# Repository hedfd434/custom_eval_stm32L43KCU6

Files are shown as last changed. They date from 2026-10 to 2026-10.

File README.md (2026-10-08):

# Custom evaluation board for stm32L432KCU6

This is a project of the custom evalution board for stm32L432KCU6.
The eval board was created for future test and prototypin during "2025/26 can-sat 🛰️ competition" organisated by ESA 🇪🇺 (European Space Agency), simultaneously it is a part of our PDR report 📑 (Preeliminary Desing Report).
By creating this board we want to show our capabilities in terms of electronics manufacturing ⚡📟.

<div style="display: flex; justify-content: center; gap: 20px;">
  <figure>
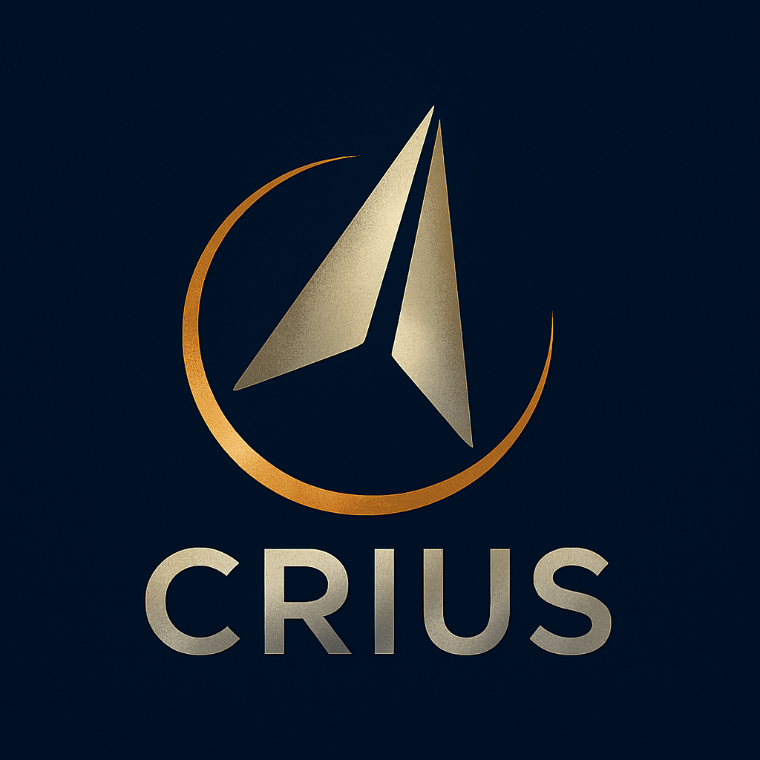
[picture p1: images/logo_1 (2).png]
    
    <figcaption style="text-align: center;">Logo of my team "Crius SPACE"</figcaption>
  </figure>
  <figure>
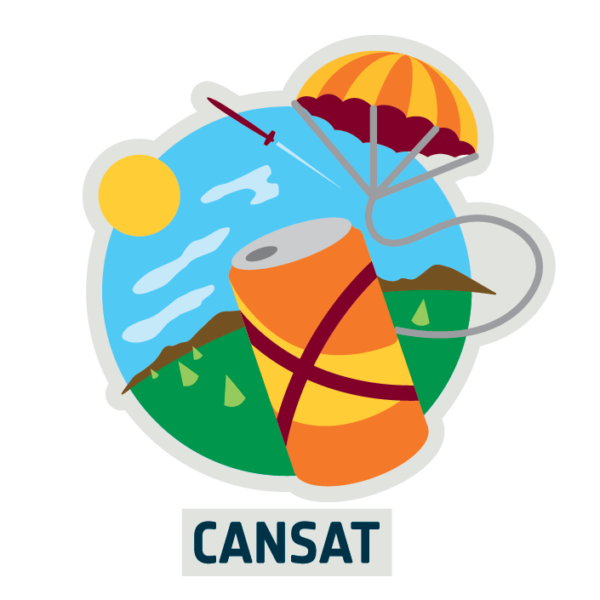
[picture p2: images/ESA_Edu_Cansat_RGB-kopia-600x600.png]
    
    <figcaption style="text-align: center;">We are taking part in can-sat competition by ESA</figcaption>
  </figure>
</div>

<div style="display: flex; justify-content: center; gap: 20px;">
  <figure>
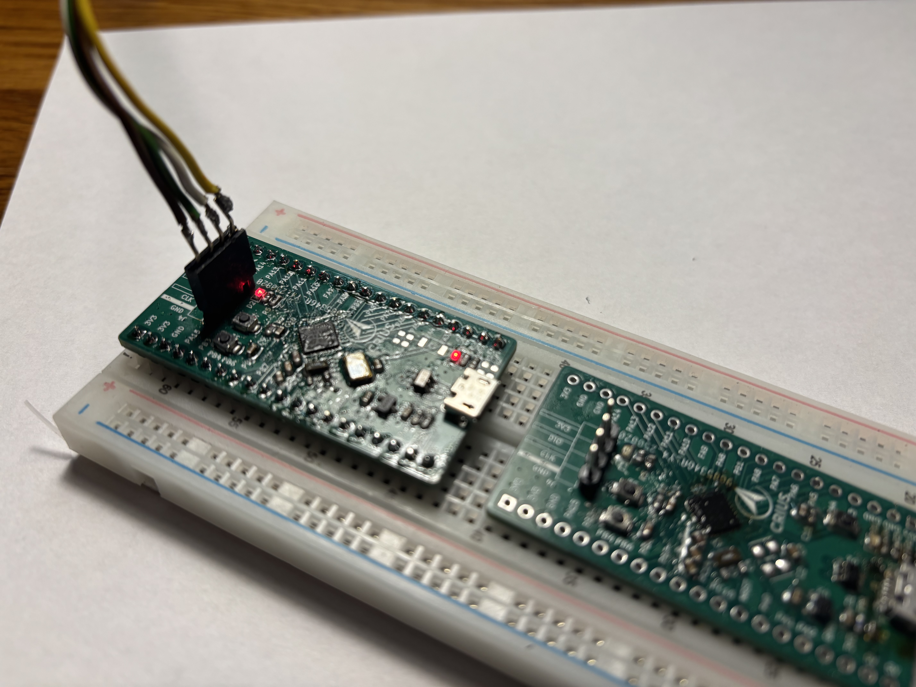
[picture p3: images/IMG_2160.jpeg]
    
    <figcaption style="text-align: center;">Real images of soldered board (running code)</figcaption>
  </figure>
  <figure>
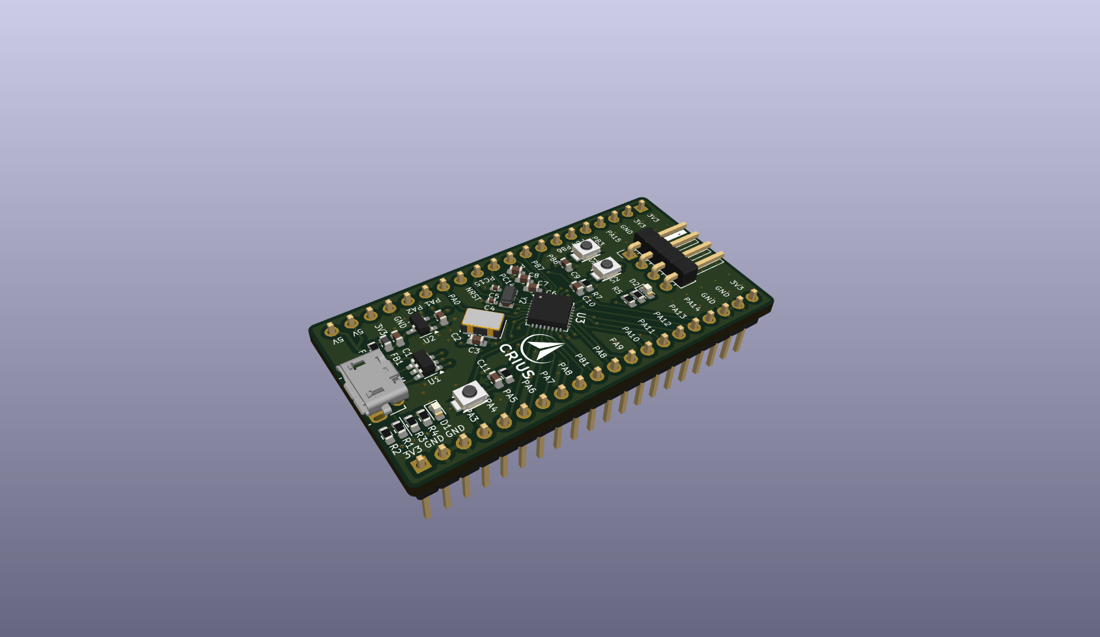
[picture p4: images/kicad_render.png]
    
    <figcaption style="text-align: center;">Render of the board in KiCAD</figcaption>
  </figure>
</div>

## future improvements, known issues and thing which are not tested
### known issues ⚠️❗:
- missing labels  - ()

- too small package - the capacitors for the LSE (Y2) are in size of 0402, (especially during manual soldering using hot-air gun or either conventional soldering iron (0603 is ratiobale limit for the size))

- space usage - board is bigger than the most popular eval boards like "blue/black pill" ❗

### probabable issues (not tested) ⚠️❗:
- reversd ESD protection for the usb (it is not necessary to use it)

### future improvements 📈🚀:
- components - no smaller than 0603 for manual soldering

- silk layer labels - complete silk layer labels

## customisation options ⚙️🛠️:
- as you can see on the photos of the real not everything is soldered:
1. 0ohm reistor on every diode - it allows you to reduce power usage in battery base aplications 🔋🪫.

2. 0ohm resistors on signal pins for usb - allows user to use pins in 2 different ways.

3. extra user button - with pull-up resistor and place for anit-debounce capacitor.

## extra files 📂:
1. stm32l432kcu6_eval_part_list.csv - file which contains list of the used elements with quantities for 1 board.

2. documentation folder - (in progress) folder which contains documentation for every component used in the project.

3. production_file_1.zip and production_file_1 - production ready files with current version of the project

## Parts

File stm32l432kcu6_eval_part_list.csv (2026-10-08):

Reference | Value | Datasheet | Footprint | Qty | LINK
C1,C2,C3,C8,C9,C10,C11 | 100nF | ~ | Capacitor_SMD:C_0603_1608Metric | 7 | https://www.tme.eu/pl/details/grm033r6ya104ke14d/kondensatory-mlcc-smd/murata/
C4,C5 | 20pF | ~ | Capacitor_SMD:C_0402_1005Metric | 2 | https://www.tme.eu/pl/details/gjm1555c1h200fb01d/kondensatory-mlcc-smd/murata/
C6 | 4.7uF | ~ | Capacitor_SMD:C_0603_1608Metric | 1 | https://www.tme.eu/pl/details/grm188r6ya475ke15d/kondensatory-mlcc-smd/murata/
C7 | 1uF | ~ | Capacitor_SMD:C_0603_1608Metric | 1 | https://www.tme.eu/pl/details/gcm188r71e105ka64d/kondensatory-mlcc-smd/murata/
D1,D2 | LED | ~ | LED_SMD:LED_0603_1608Metric | 2 | null (different colours)
F1 | 250mA | ~ | Fuse:Fuse_0603_1608Metric | 1 | https://www.tme.eu/pl/en/details/tr-0603fa250-r/0603-smd-fuses-ultra-fast/eaton-bussmann/
FB1 | value | ~ | Inductor_SMD:L_0603_1608Metric | 1 | https://www.tme.eu/pl/details/blm18ba470sn1d/ferryty-koraliki/murata/
J1 | USB_B_Micro | ~ | Connector_USB:USB_Micro-B_Molex-105017-0001 | 1 | https://www.tme.eu/pl/en/details/mx-105017-0001/usb-ieee1394-connectors/molex/105017-0001/
J2,J3 | Conn_01x20_Pin | ~ | Connector_PinHeader_2.54mm:PinHeader_1x20_P2.54mm_Vertical | 2 | null
J4 | Conn_01x04_Pin | ~ | Connector_PinHeader_2.54mm:PinHeader_1x04_P2.54mm_Horizontal | 1 | null
R1,R2,R3,R5,R8 | 0ohm | ~ | Resistor_SMD:R_0603_1608Metric | 3 | https://www.tme.eu/pl/details/smd0603-0r/rezystory-smd/royalohm/0603saj0000t5e/
R4,R6 | 1K | ~ | Resistor_SMD:R_0603_1608Metric | 2 | https://www.tme.eu/pl/details/0201wmf1001tee/rezystory-smd/royalohm/
R7 | 10K | ~ | Resistor_SMD:R_0603_1608Metric | 1 | https://www.tme.eu/pl/details/b3u-1000pm/mikroprzelaczniki-tact/omron-electronic-components/
S1,S2,S3 | B3U-1000PM | https://omronfs.omron.com/en_US/ecb/products/pdf/en-b3u.pdf | custom_part_library_1:B3U1000PM_3D_MODEL | 3 | https://www.tme.eu/pl/details/usblc6-2sc6y/diody-zabezpieczajace-drabinki/stmicroelectronics/
U1 | USBLC6-2SC6 | https://www.st.com/resource/en/datasheet/usblc6-2.pdf | Package_TO_SOT_SMD:SOT-23-6 | 1 | https://www.tme.eu/pl/en/details/usblc6-2sc6/protection-diodes-arrays/stmicroelectronics/
U2 | XC6206PxxxMR | https://www.torexsemi.com/file/xc6206/XC6206.pdf | Package_TO_SOT_SMD:SOT-23-3 | 1 | https://www.tme.eu/pl/details/xc6206p332mr-g/stabilizatory-napiecia-nieregulowane-ldo/torex/
U3 | STM32L432KCUx | https://www.st.com/resource/en/datasheet/stm32l432kc.pdf | Package_DFN_QFN:QFN-32-1EP_5x5mm_P0.5mm_EP3.65x3.65mm_ThermalVias | 1 | null
Y1 | ASFL1-40.000MHZ-EC-T | https://abracon.com/Oscillators/ASFL1.pdf | ASFL1 | 1 | null
Y2 | FC-135_32.7680KA-A3_12_5_pF | https://support.epson.biz/td/api/doc_check.php?dl=brief_fc-135r_en.pdf | FC_135_CLOCK_KI_CAD:FC-135_32_7680KA-A3 | 1 | ali (12.5pF)

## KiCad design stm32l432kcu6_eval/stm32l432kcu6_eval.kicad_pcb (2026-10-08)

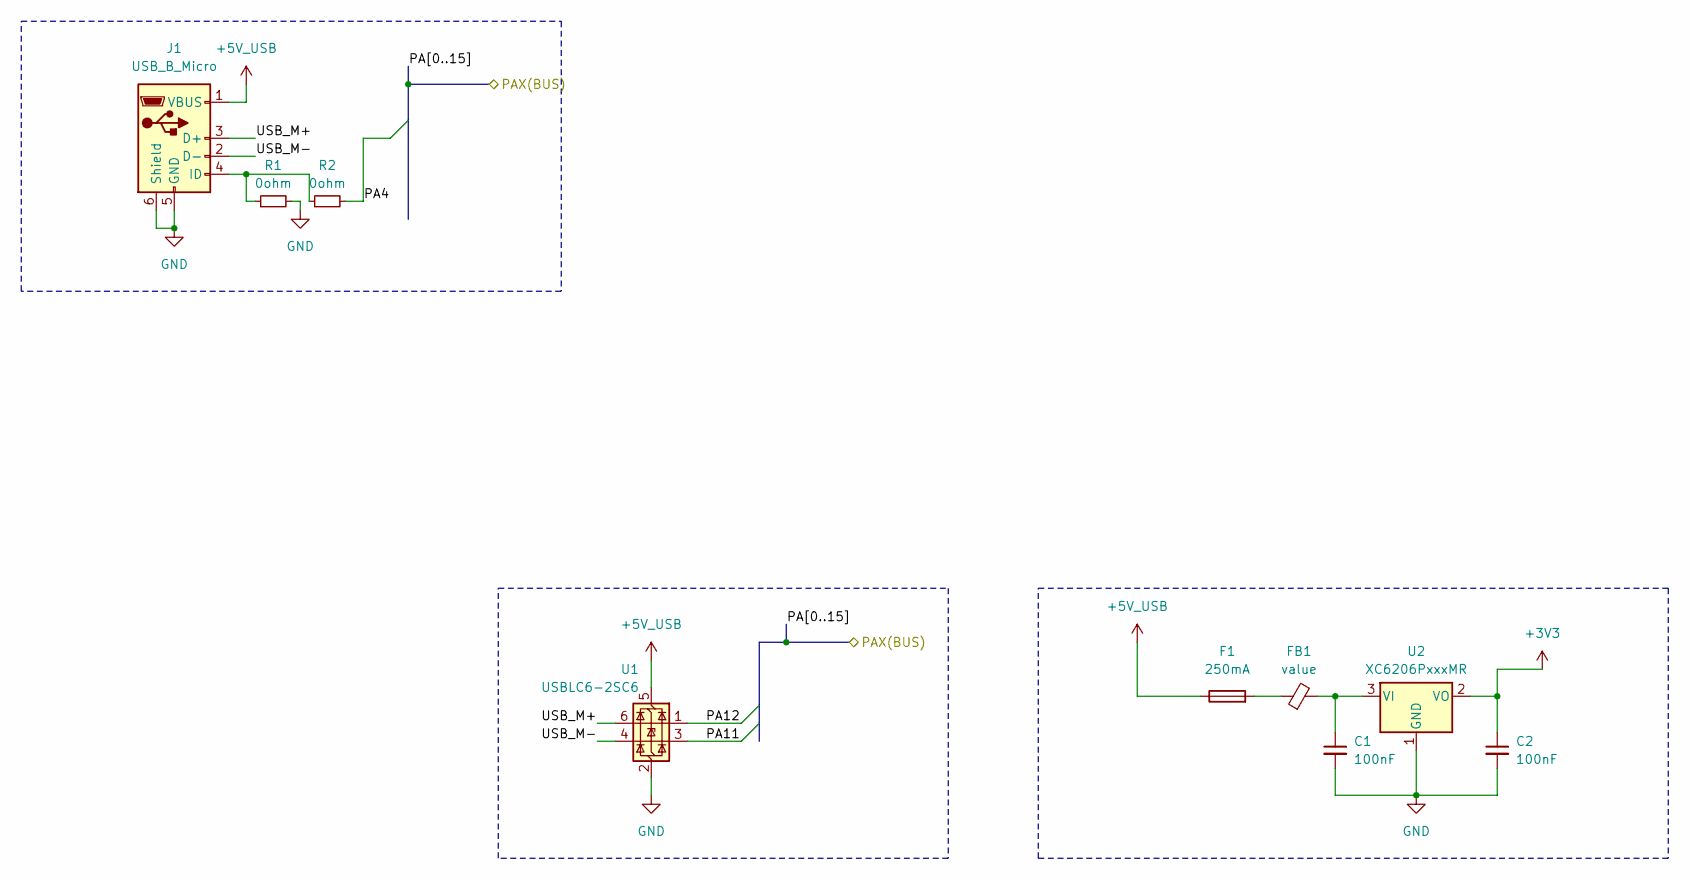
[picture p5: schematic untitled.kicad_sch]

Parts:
C1, C2: 100nF; C_0603_1608Metric
F1: 250mA; Fuse_0603_1608Metric
FB1: value; L_0603_1608Metric
J1: USB_B_Micro; USB_Micro-B_Molex-105017-0001
R1, R2: 0ohm; R_0603_1608Metric
U1: USBLC6-2SC6; SOT-23-6
U2: XC6206PxxxMR; SOT-23-3

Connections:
+3V3: C2.1, U2.2 (VO); also elsewhere on the board
+5V_USB: F1.1, J1.1 (VBUS), U1.5 (VBUS); also elsewhere on the board
/connectors_gpios_2_5_4/PA4: R2.2; also elsewhere on the board
/connectors_gpios_2_5_4/PA11: U1.3 (I/O2); also elsewhere on the board
/connectors_gpios_2_5_4/PA12: U1.1 (I/O1); also elsewhere on the board
/power_usb/USB_M+: J1.3 (D+), U1.6 (I/O1)
/power_usb/USB_M-: J1.2 (D-), U1.4 (I/O2)
GND: C1.2, C2.2, J1.5 (GND), J1.6 (Shield), R1.2, U1.2 (GND), U2.1 (GND); also elsewhere on the board
unnamed: F1.2, FB1.1
unnamed: J1.4 (ID), R1.1, R2.1
unnamed: C1.1, FB1.2, U2.3 (VI)

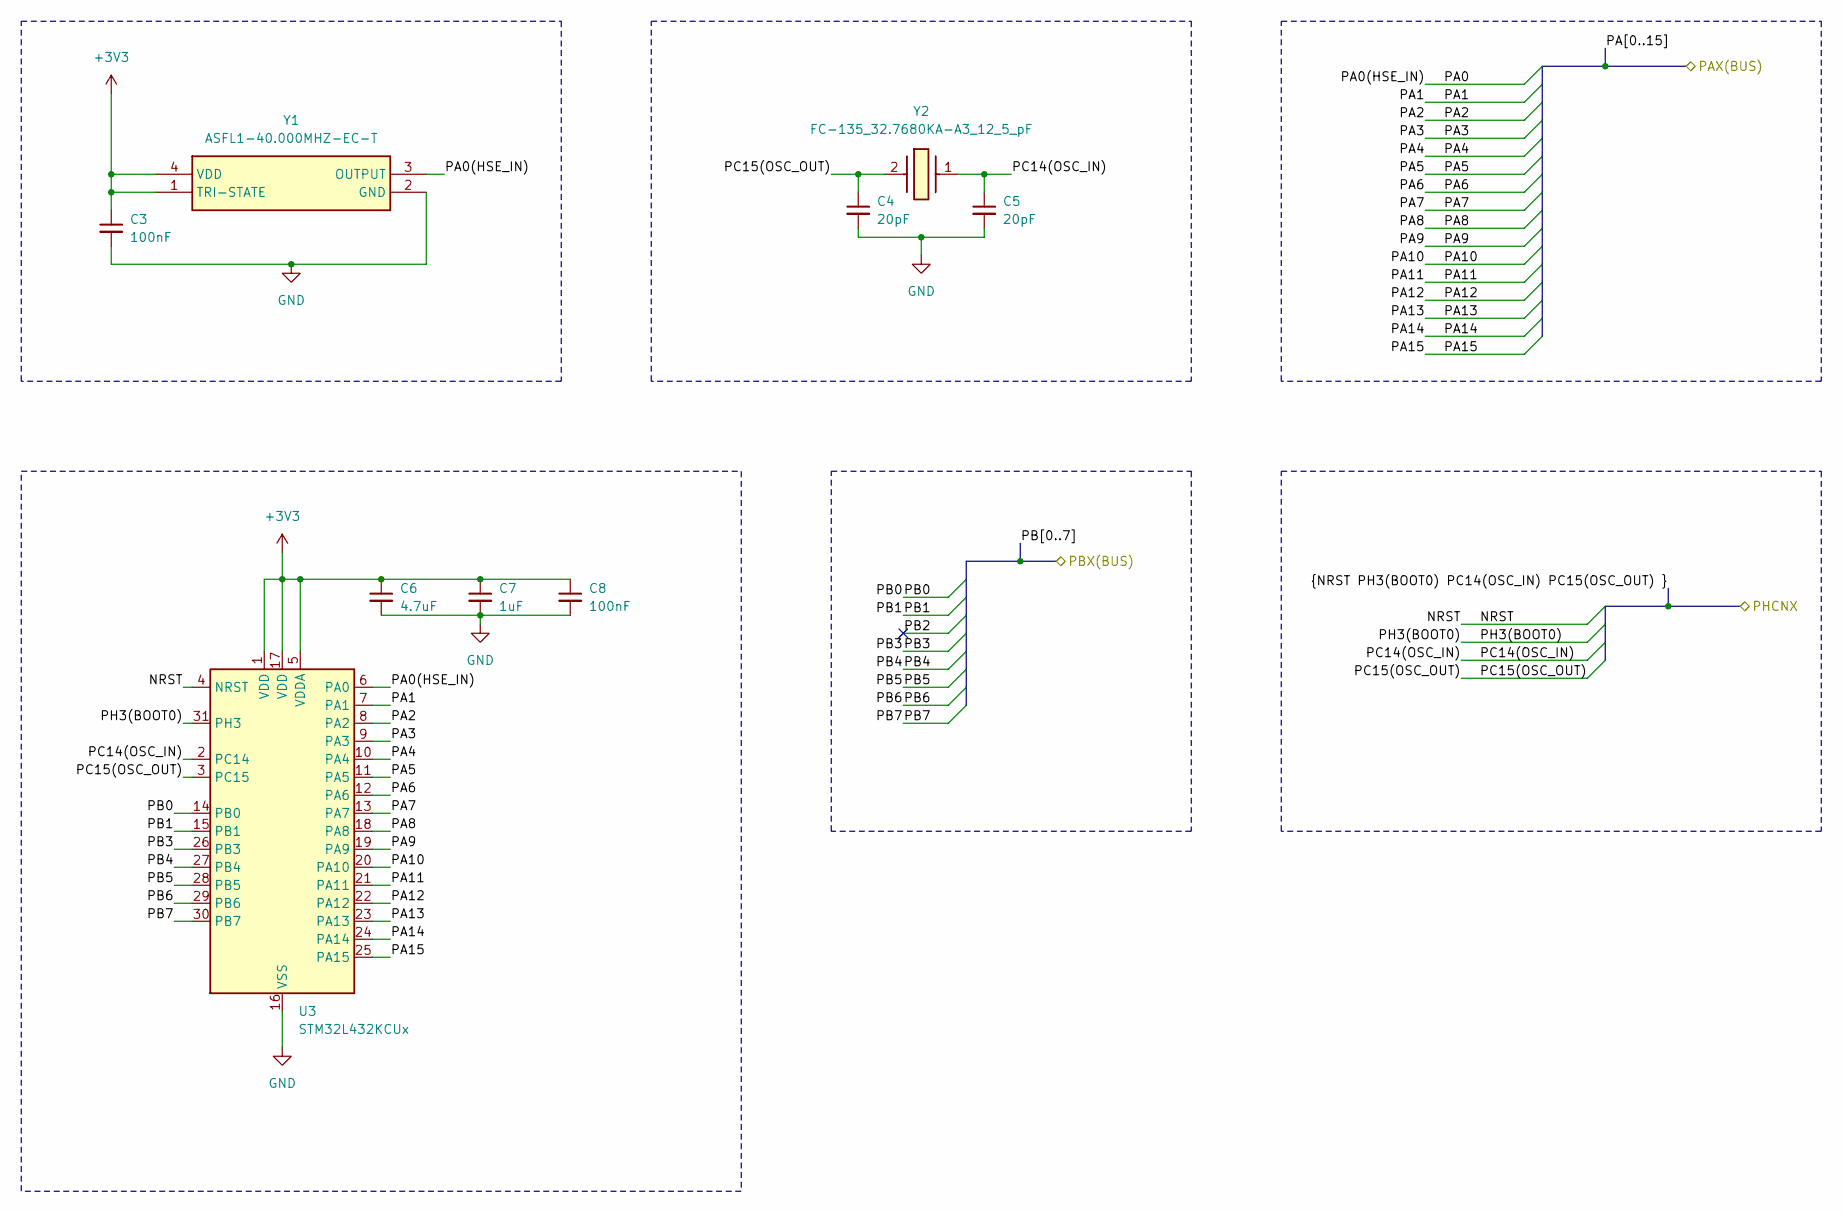
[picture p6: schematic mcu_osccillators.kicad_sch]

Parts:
C3, C8: 100nF; C_0603_1608Metric
C4, C5: 20pF; C_0402_1005Metric
C6: 4.7uF; C_0603_1608Metric
C7: 1uF; C_0603_1608Metric
U3: STM32L432KCUx; QFN-32-1EP_5x5mm_P0.5mm_EP3.65x3.65mm_ThermalVias
Y1: ASFL1-40.000MHZ-EC-T; ASFL1; Mouser Part Number 815-ASFL1-40.0-EC-T
Y2: FC-135_32.7680KA-A3_12_5_pF; FC-135_32_7680KA-A3; Mouser Part Number 732-FC135-32.76KAA3

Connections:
+3V3: C3.1, C6.1, C7.1, C8.1, U3.1 (VDD), U3.5 (VDDA), U3.17 (VDD), Y1.1 (TRI-STATE), Y1.4 (VDD); also elsewhere on the board
/connectors_gpios_2_5_4/NRST: U3.4 (NRST); also elsewhere on the board
/connectors_gpios_2_5_4/PA0: U3.6 (PA0), Y1.3 (OUTPUT); also elsewhere on the board
/connectors_gpios_2_5_4/PA1: U3.7 (PA1); also elsewhere on the board
/connectors_gpios_2_5_4/PA2: U3.8 (PA2); also elsewhere on the board
/connectors_gpios_2_5_4/PA3: U3.9 (PA3); also elsewhere on the board
/connectors_gpios_2_5_4/PA4: U3.10 (PA4); also elsewhere on the board
/connectors_gpios_2_5_4/PA5: U3.11 (PA5); also elsewhere on the board
/connectors_gpios_2_5_4/PA6: U3.12 (PA6); also elsewhere on the board
/connectors_gpios_2_5_4/PA7: U3.13 (PA7); also elsewhere on the board
/connectors_gpios_2_5_4/PA8: U3.18 (PA8); also elsewhere on the board
/connectors_gpios_2_5_4/PA9: U3.19 (PA9); also elsewhere on the board
/connectors_gpios_2_5_4/PA10: U3.20 (PA10); also elsewhere on the board
/connectors_gpios_2_5_4/PA11: U3.21 (PA11); also elsewhere on the board
/connectors_gpios_2_5_4/PA12: U3.22 (PA12); also elsewhere on the board
/connectors_gpios_2_5_4/PA13: U3.23 (PA13); also elsewhere on the board
/connectors_gpios_2_5_4/PA14: U3.24 (PA14); also elsewhere on the board
/connectors_gpios_2_5_4/PA15: U3.25 (PA15); also elsewhere on the board
/connectors_gpios_2_5_4/PB0: U3.14 (PB0); also elsewhere on the board
/connectors_gpios_2_5_4/PB1: U3.15 (PB1); also elsewhere on the board
/connectors_gpios_2_5_4/PB3: U3.26 (PB3); also elsewhere on the board
/connectors_gpios_2_5_4/PB4: U3.27 (PB4); also elsewhere on the board
/connectors_gpios_2_5_4/PB5: U3.28 (PB5); also elsewhere on the board
/connectors_gpios_2_5_4/PB6: U3.29 (PB6); also elsewhere on the board
/connectors_gpios_2_5_4/PB7: U3.30 (PB7); also elsewhere on the board
/connectors_gpios_2_5_4/PC14(OSC_IN): C5.1, U3.2 (PC14), Y2.1; also elsewhere on the board
/connectors_gpios_2_5_4/PC15(OSC_OUT): C4.1, U3.3 (PC15), Y2.2 (X2); also elsewhere on the board
/connectors_gpios_2_5_4/PH3(BOOT0): U3.31 (PH3); also elsewhere on the board
GND: C3.2, C4.2, C5.2, C6.2, C7.2, C8.2, U3.16 (VSS), U3.32 (VSS), U3.33 (VSS), Y1.2 (GND); also elsewhere on the board

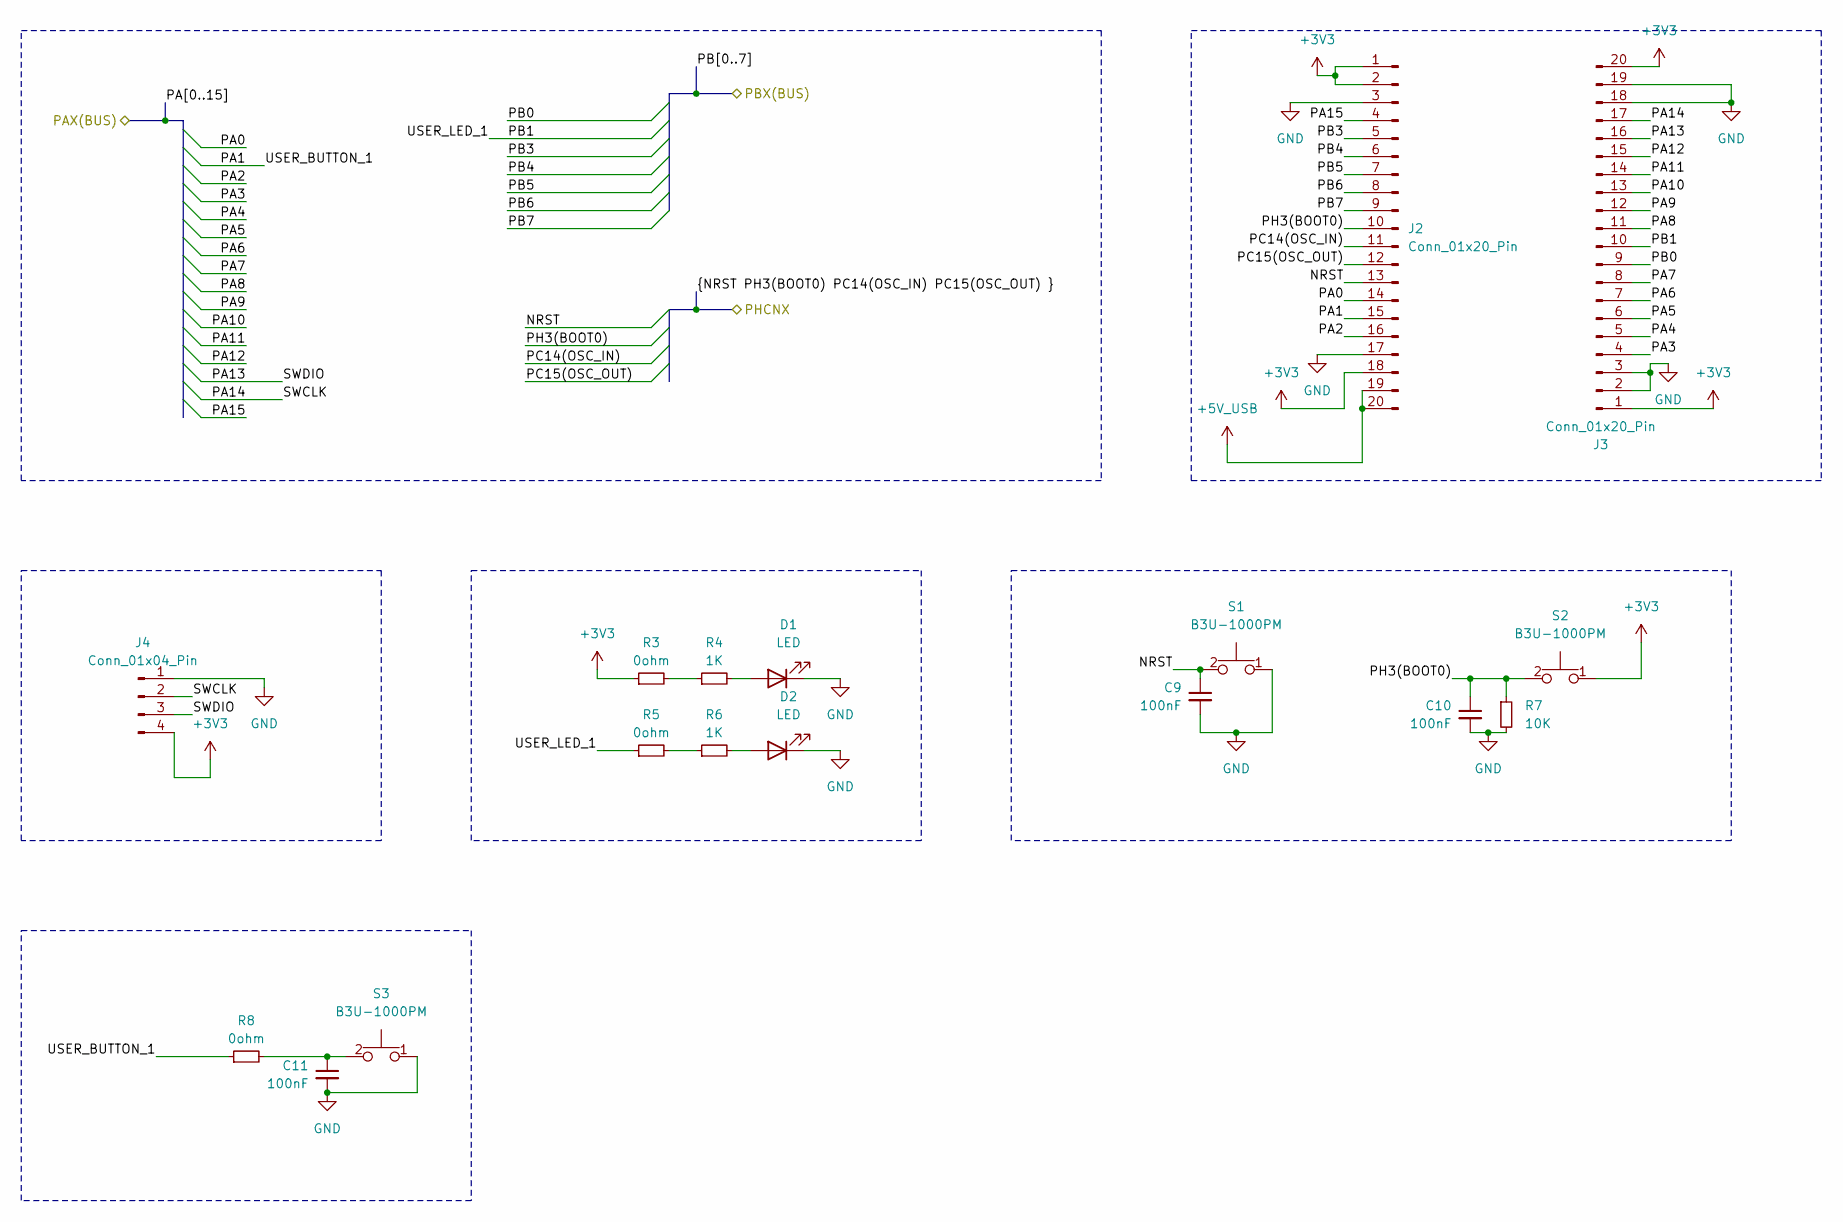
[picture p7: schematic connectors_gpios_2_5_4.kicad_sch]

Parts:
C9, C10, C11: 100nF; C_0603_1608Metric
D1, D2: LED; LED_0603_1608Metric
J2, J3: Conn_01x20_Pin; PinHeader_1x20_P2.54mm_Vertical
J4: Conn_01x04_Pin; PinHeader_1x04_P2.54mm_Horizontal
R3, R5, R8: 0ohm; R_0603_1608Metric
R4, R6: 1K; R_0603_1608Metric
R7: 10K; R_0603_1608Metric
S1, S2, S3: B3U-1000PM; B3U1000PM_3D_MODEL; Manufacturer_Part_Number B3U-1000PM

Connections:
+3V3: J2.1, J2.2, J2.18, J3.1, J3.20, J4.4, R3.1, S2.1; also elsewhere on the board
+5V_USB: J2.19, J2.20; also elsewhere on the board
/connectors_gpios_2_5_4/NRST: C9.1, J2.13, S1.2; also elsewhere on the board
/connectors_gpios_2_5_4/PA0: J2.14; also elsewhere on the board
/connectors_gpios_2_5_4/PA1: J2.15, R8.1; also elsewhere on the board
/connectors_gpios_2_5_4/PA2: J2.16; also elsewhere on the board
/connectors_gpios_2_5_4/PA3: J3.4; also elsewhere on the board
/connectors_gpios_2_5_4/PA4: J3.5; also elsewhere on the board
/connectors_gpios_2_5_4/PA5: J3.6; also elsewhere on the board
/connectors_gpios_2_5_4/PA6: J3.7; also elsewhere on the board
/connectors_gpios_2_5_4/PA7: J3.8; also elsewhere on the board
/connectors_gpios_2_5_4/PA8: J3.11; also elsewhere on the board
/connectors_gpios_2_5_4/PA9: J3.12; also elsewhere on the board
/connectors_gpios_2_5_4/PA10: J3.13; also elsewhere on the board
/connectors_gpios_2_5_4/PA11: J3.14; also elsewhere on the board
/connectors_gpios_2_5_4/PA12: J3.15; also elsewhere on the board
/connectors_gpios_2_5_4/PA13: J3.16, J4.3; also elsewhere on the board
/connectors_gpios_2_5_4/PA14: J3.17, J4.2; also elsewhere on the board
/connectors_gpios_2_5_4/PA15: J2.4; also elsewhere on the board
/connectors_gpios_2_5_4/PB0: J3.9; also elsewhere on the board
/connectors_gpios_2_5_4/PB1: J3.10, R5.1; also elsewhere on the board
/connectors_gpios_2_5_4/PB3: J2.5; also elsewhere on the board
/connectors_gpios_2_5_4/PB4: J2.6; also elsewhere on the board
/connectors_gpios_2_5_4/PB5: J2.7; also elsewhere on the board
/connectors_gpios_2_5_4/PB6: J2.8; also elsewhere on the board
/connectors_gpios_2_5_4/PB7: J2.9; also elsewhere on the board
/connectors_gpios_2_5_4/PC14(OSC_IN): J2.11; also elsewhere on the board
/connectors_gpios_2_5_4/PC15(OSC_OUT): J2.12; also elsewhere on the board
/connectors_gpios_2_5_4/PH3(BOOT0): C10.1, J2.10, R7.1, S2.2; also elsewhere on the board
GND: C9.2, C10.2, C11.2, D1.1 (K), D2.1 (K), J2.3, J2.17, J3.2, J3.3, J3.18, J3.19, J4.1, R7.2, S1.1, S3.1; also elsewhere on the board
unnamed: C11.1, R8.2, S3.2
unnamed: D1.2 (A), R4.2
unnamed: D2.2 (A), R6.2
unnamed: R3.2, R4.1
unnamed: R5.2, R6.1

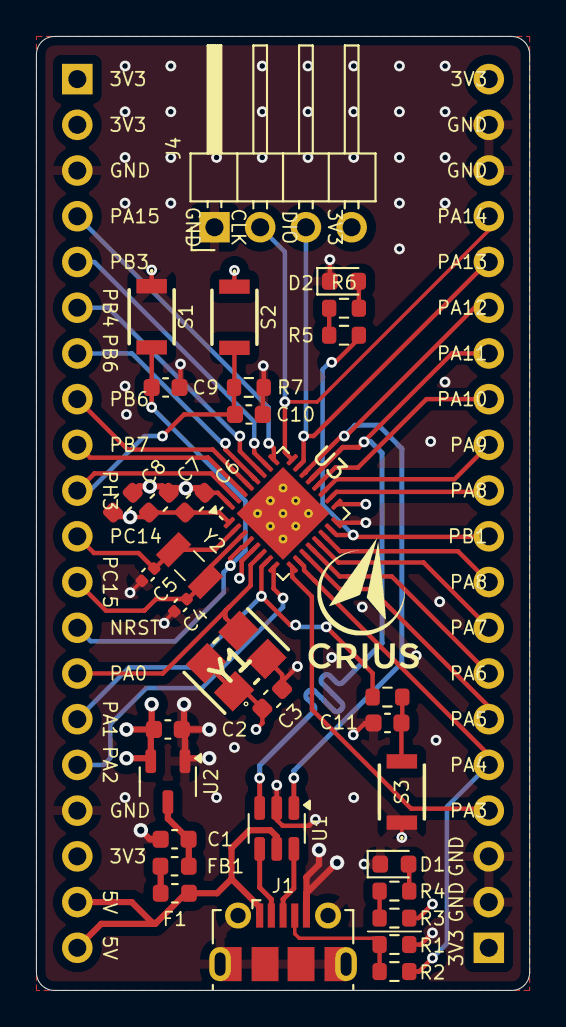
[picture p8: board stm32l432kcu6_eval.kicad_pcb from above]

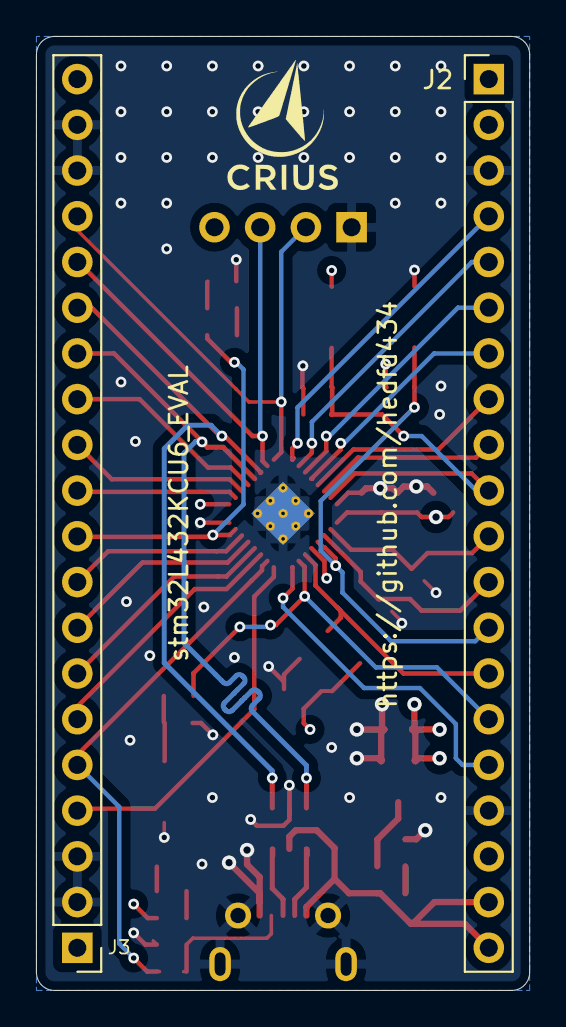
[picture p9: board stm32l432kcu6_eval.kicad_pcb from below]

Board: 4 copper layers, 27.4 x 53.0 mm, 35 parts (2 on the bottom side), 40 nets.
